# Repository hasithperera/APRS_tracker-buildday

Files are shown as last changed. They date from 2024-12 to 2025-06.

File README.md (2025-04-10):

# APRS tracker-build day

- This project is designed as an out reach project under the WVU Amateur radio club - High altitude ballooning grand awarded Fall 2024
- The main goal was to design a system allowing users to send APRS location packets

---
## V1.1 - APRS beacon

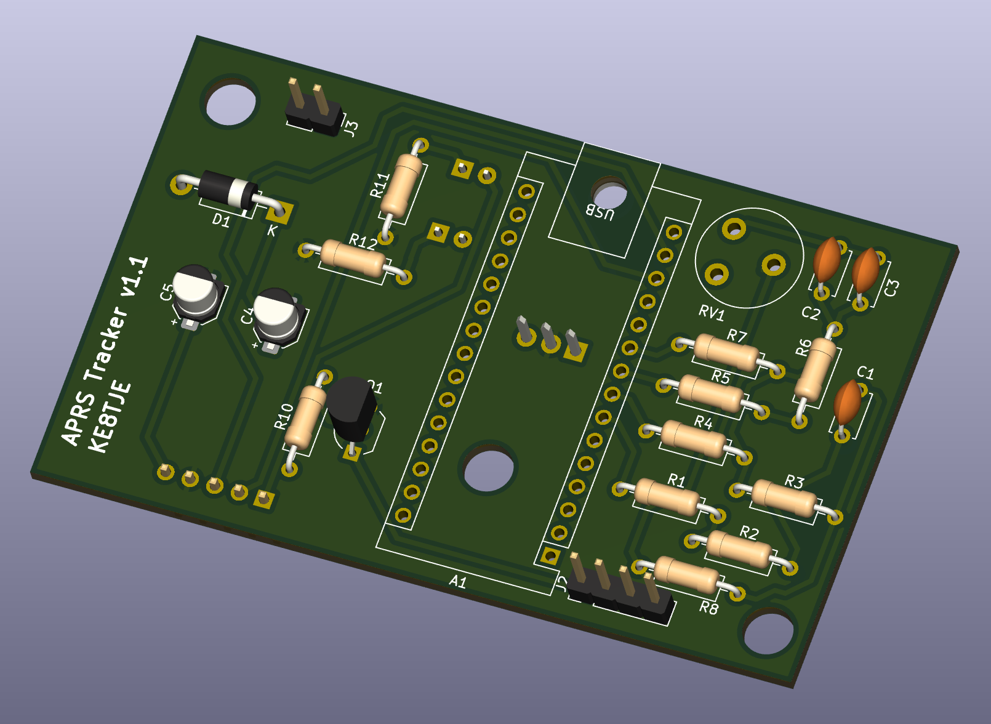
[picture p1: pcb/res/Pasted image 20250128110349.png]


- [Build instructions](pcb/README.md) - Partially completed
---
## Bluetooth KISS TNC - v 1.0

- Based on the interest, we added a part 2 for the build day that was developed for advanced users who needed APRS decode capabilities.
- A self powered KISS TNC PCB was designed to carry existing firmware.
	- Initial testing with APRSDroid and YAAC showed promising results
- V1 PCB for the APRS KISS TNC 

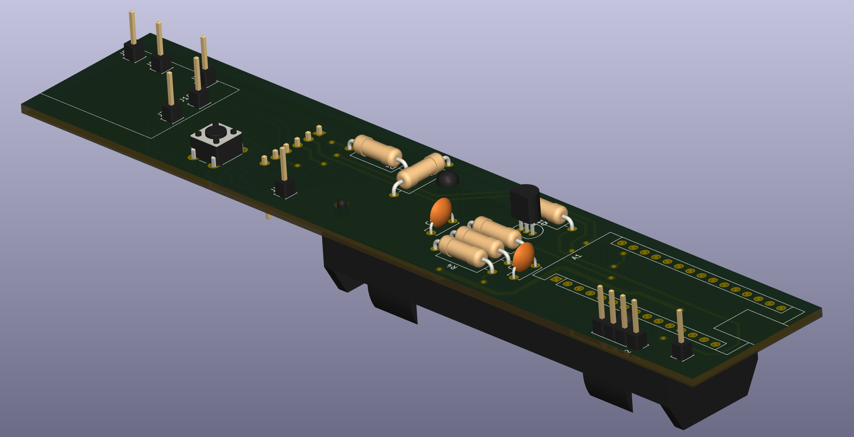
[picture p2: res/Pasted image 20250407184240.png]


---
## Project progress

- November 2024 - Reached out to local clubs on interest and participation
- December 2024 - Basic prototype was tested 
- January 2025 - v1.1 production 
- March 2025 - Software was finalized to allow consistent operation 
- April 2025 - BT KISS TNC v1 PCB added 

*Last edited: April 09 by KE8TJE*

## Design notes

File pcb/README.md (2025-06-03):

# PCB Design updates 

## V1.1 



---
## Build guide 

- Follow the component list below and populate the PCB with components 
- Note 2 changes:
	- the 2N2222 needs to be replaced by a BS170 MOSFET
	- Bridge the Pins **D2** and **D3** on the Arduino
- Once you have every thing soldered in connect power via the USB C connector
	- You should see the power led light up on the arduino
	- Power led on the GPS module
- Once you have confirmed power to all the components follow the programming guide 

---
## Component list

| **Symbol** | **Value** |
| --- | --- |
| C1 | 100n |
| C2,C3 | 4.7u |
| C3,C4 | pol smd |
| D1 | 1n4001 |
| Q1 | 2N2222/BS170 |
| R1 | 6.2k |
| R2 | 2k |
| R3 | 270 |
| R4 | 3.9k |
| R5 | 1.2k |
| R6-R8 | 1k |
| R10 | 2.7k |
| R11,R12 | 330 |

---
## Program instructions

- Open up the Arduino code provided
- to install the Aprs library go to: Tools > Manage Libraries....
	- Search for `LibAPRS` and install the library by Baris DINC
- Once you have the library installed compile the program and it should compile without errors
- Change `line 45` to add your call
### Basic radio interface testing

- Once the Arduino is properly programmed on power on the Radio will be keyed up 2 times as a test. 
	- If this step fails: check your connectors and check your MOSFET.
- To test the system indoors without GPS lock uncomment `line 30`, this will enable a simulate mode where GPS data is being. artificially provided 
- Once the second count reaches the value set in `APRS_TX_offset_utc_sec` your radio will transmit an APRS packet.
	- Radio should key down automatically
	- It has been repoted with some radios this may not happen and this was often observed when there was an extended length of cable involved
		- adding a ferrite bead would potentially solve the issue
		- if not using a separate external antenna should help
- NOTE: change the `APRS_TX_offset_utc_sec` to some random value. This is the time your specific APRS unit will transmit. Since its on simplex we don't want every one to TX at the same time. 
- once you have completed testing comment out `line 30` congratulations now you have a working APRS beacon 

if you have questions please reach out to KE8TJE

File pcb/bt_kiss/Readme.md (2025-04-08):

- The Bluetooth KISS TNC implementation schematic and board designs for quick access

## Schematic 

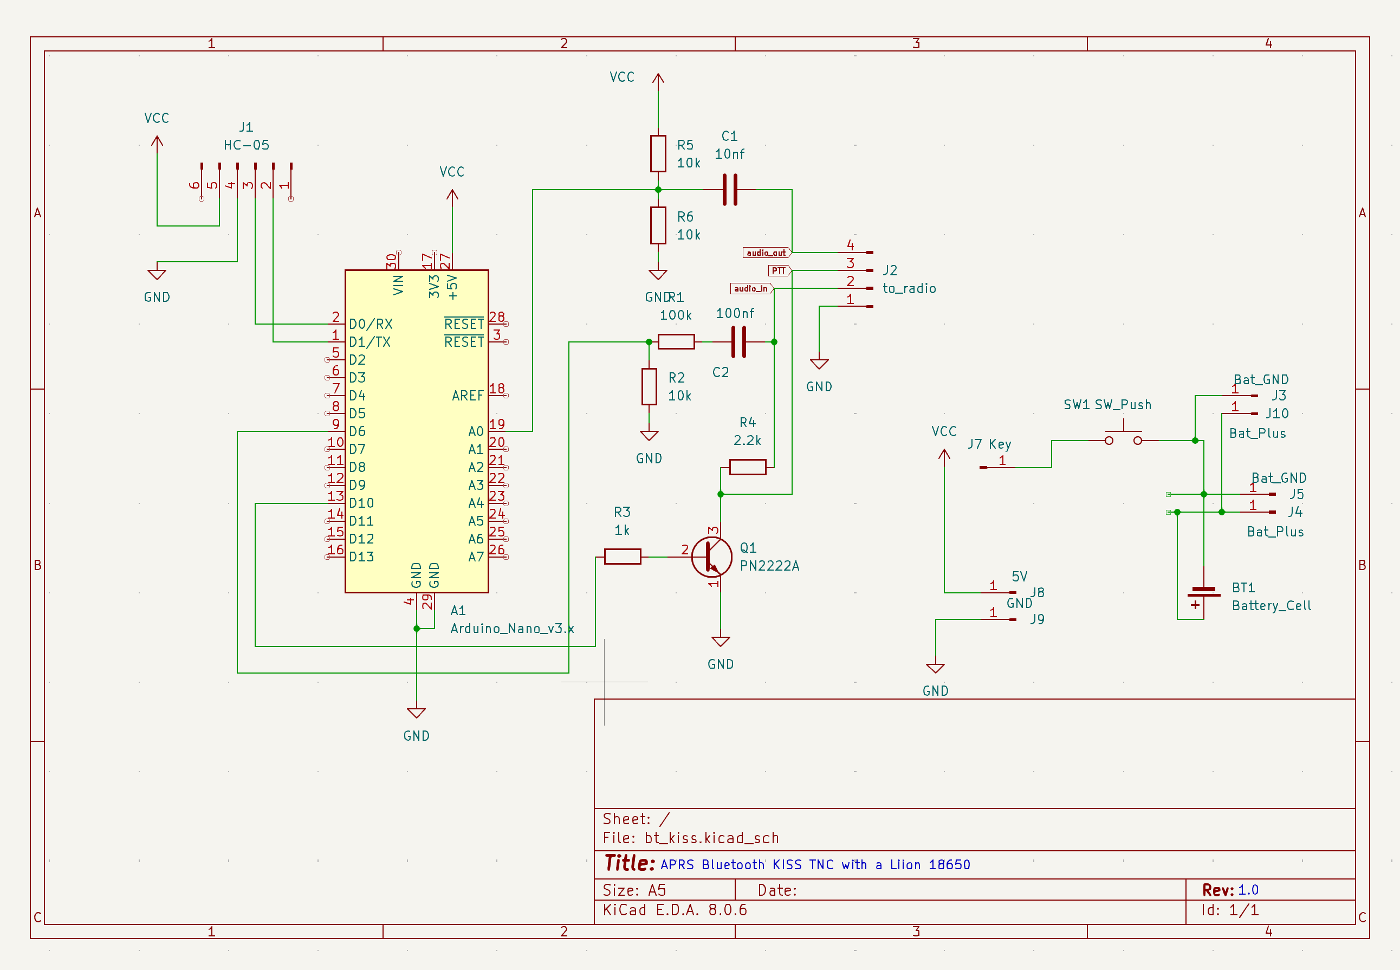
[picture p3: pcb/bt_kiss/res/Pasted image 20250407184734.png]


## Program instructions

- Firmware found [here](https://raw.githubusercontent.com/mobilinkd/tnc1/arduino/images/mobilinkd-473-arduino.hex)
- Programming using the com port: `avrdude -c arduino -p m328p -P /dev/ttyUSB1 -b 57600 -U mobilinkd-473-arduino.hex`
- Programming using a USBasp: `avrdude -p m328p -c usbasp -U flash:w:<filename>.hex`

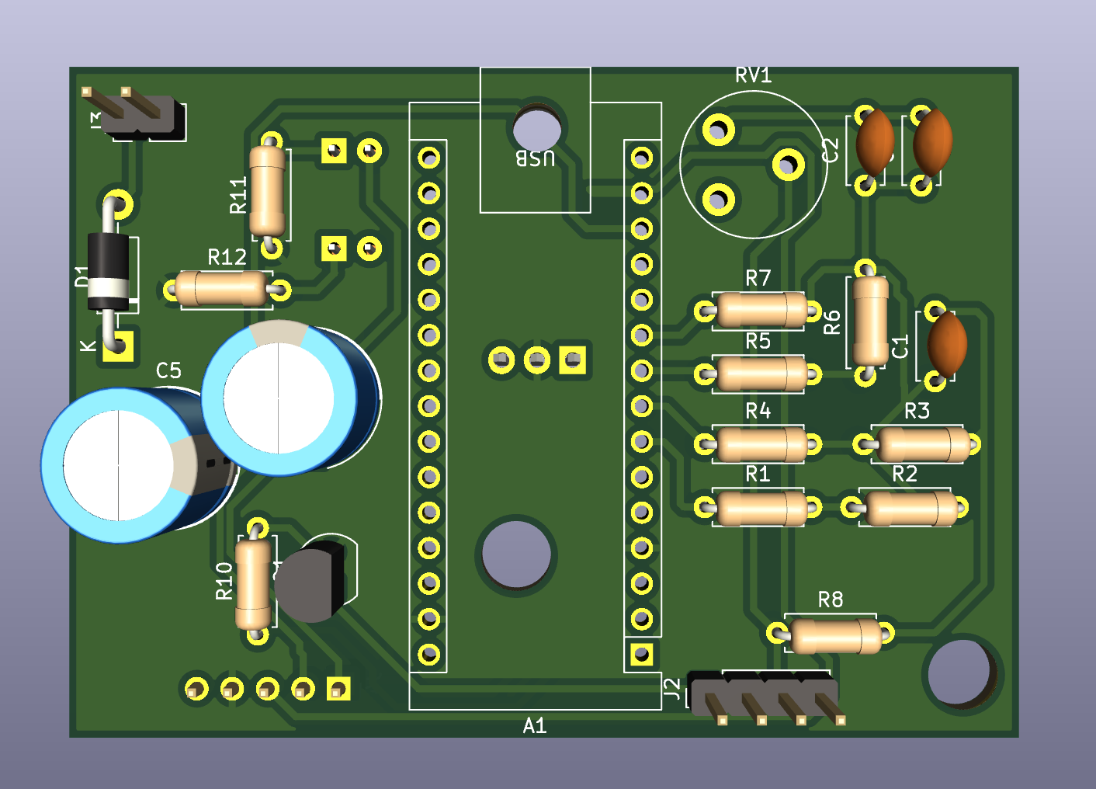
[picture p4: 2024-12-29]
pcb/res/Pasted image 20241229175545.png

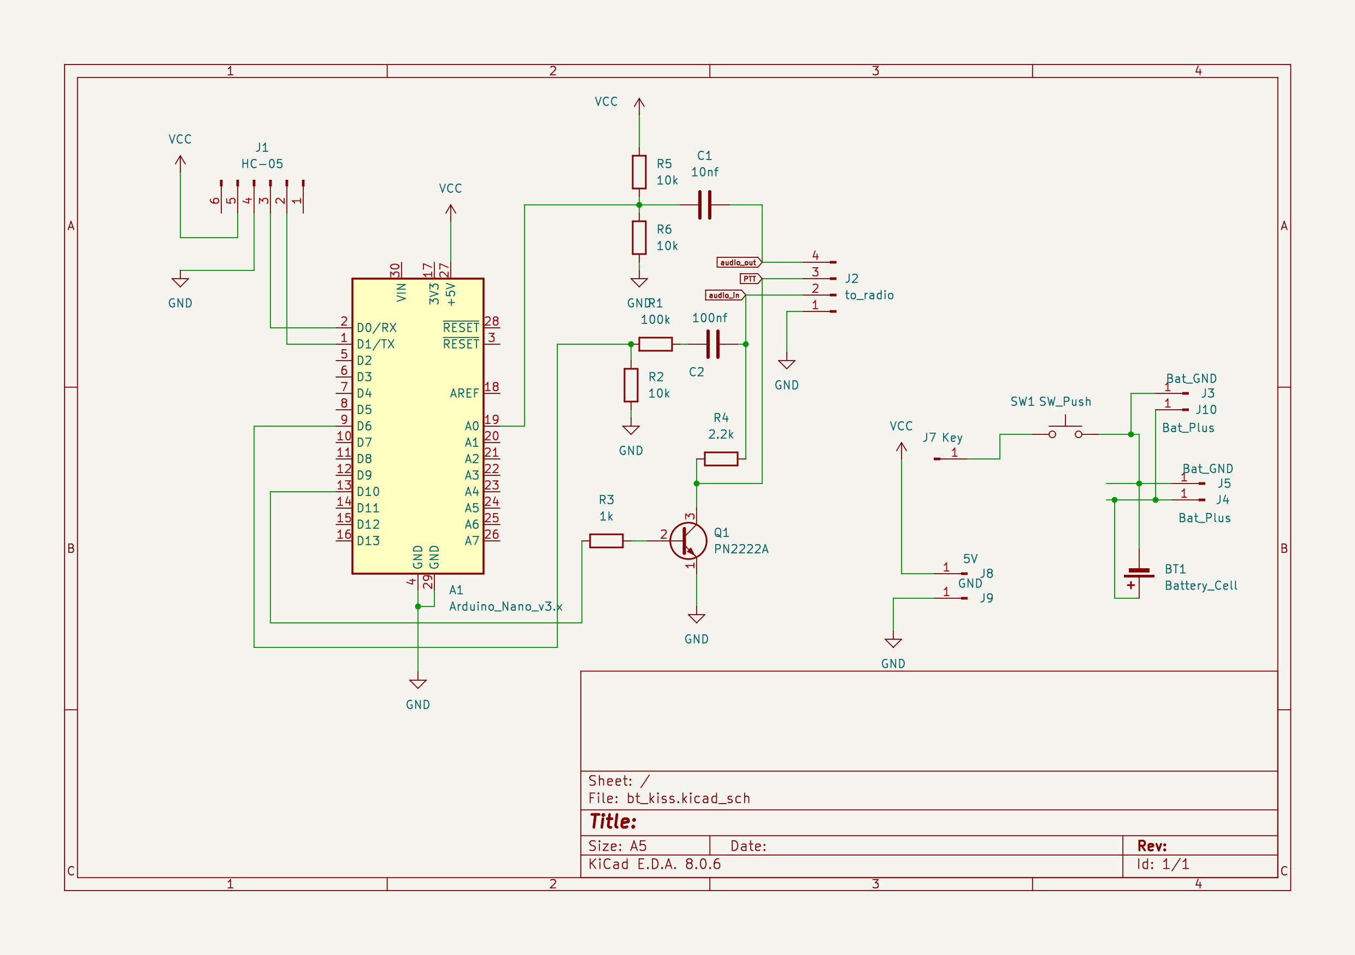
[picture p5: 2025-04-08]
res/Pasted image 20250407184228.png

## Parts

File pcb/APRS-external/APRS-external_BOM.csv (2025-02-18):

Id | Designator | Footprint | Quantity | Designation | Supplier and ref
1 | R8,R7,R6 | R_Axial_DIN0207_L6.3mm_D2.5mm_P10.16mm_Horizontal | 3 | 1k
2 | C5,C4 | CP_Elec_4x4.5 | 2 | C_Polarized
3 | RV1 | Potentiometer_Piher_PT-10-V05_Vertical | 1 | R_Potentiometer_US
4 | R11,R12 | R_Axial_DIN0207_L6.3mm_D2.5mm_P10.16mm_Horizontal | 2 | 330
5 | C2,C3 | D_0805_2012Metric_Pad1.15x1.40mm_HandSolder | 2 | 4.7u
6 | R10 | R_Axial_DIN0207_L6.3mm_D2.5mm_P10.16mm_Horizontal | 1 | 2.7k
7 | R1 | R_Axial_DIN0207_L6.3mm_D2.5mm_P10.16mm_Horizontal | 1 | 6.2k
8 | R4 | R_Axial_DIN0207_L6.3mm_D2.5mm_P10.16mm_Horizontal | 1 | 3.9k
9 | J3 | PinHeader_1x02_P2.54mm_Vertical | 1 | Ext Power
10 | R5 | R_Axial_DIN0207_L6.3mm_D2.5mm_P10.16mm_Horizontal | 1 | 1.2k
11 | D1 | D_DO-41_SOD81_P10.16mm_Horizontal | 1 | 1N4001
12 | C1 | D_0805_2012Metric_Pad1.15x1.40mm_HandSolder | 1 | 100n
13 | A1 | Arduino_Nano | 1 | Arduino_Nano_v2.x
14 | R3 | R_Axial_DIN0207_L6.3mm_D2.5mm_P10.16mm_Horizontal | 1 | 270
15 | J2 | PinHeader_1x04_P2.54mm_Vertical | 1 | To-Radio
16 | Q1 | TO-92_Inline_Wide | 1 | 2N2222
17 | R2 | R_Axial_DIN0207_L6.3mm_D2.5mm_P10.16mm_Horizontal | 1 | 2k
18 | J4 | PinHeader_1x05_P2.54mm_Vertical | 1 | GPS
19 | D3,D2 | LED_D5.0mm | 2 | LED
20 | U1 | TO-220-3_Horizontal_TabDown | 1 | L7805

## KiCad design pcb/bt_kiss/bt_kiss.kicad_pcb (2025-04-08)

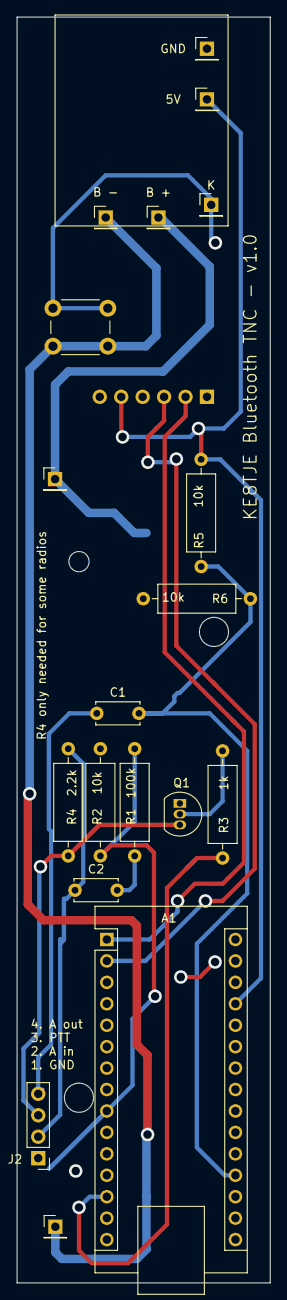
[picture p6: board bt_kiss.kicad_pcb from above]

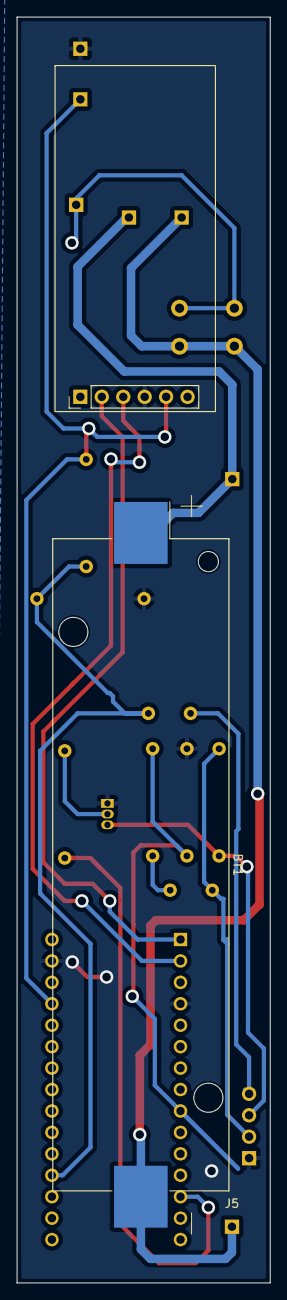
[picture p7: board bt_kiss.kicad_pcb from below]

Board: 2 copper layers, 30.0 x 150.0 mm, 21 parts (2 on the bottom side), 15 nets.

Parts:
5V: 5V; PinHeader_1x01_P2.54mm_Vertical
A1: Arduino_Nano_v3.x; Arduino_Nano
B +: Bat_Plus; PinHeader_1x01_P2.54mm_Vertical
B -: Bat_GND; PinHeader_1x01_P2.54mm_Vertical
BT1: Battery_Cell; BatteryHolder_Keystone_1042_1x18650
C1: 10nf; C_Disc_D5.0mm_W2.5mm_P5.00mm
C2: 100nf; C_Disc_D5.0mm_W2.5mm_P5.00mm
GND: GND; PinHeader_1x01_P2.54mm_Vertical
J1: HC-05; PinHeader_1x06_P2.54mm_Vertical
J2: to_radio; PinHeader_1x04_P2.54mm_Vertical
J4: Bat_Plus; PinHeader_1x01_P2.54mm_Vertical
J5: Bat_GND; PinHeader_1x01_P2.54mm_Vertical
K: Key; PinHeader_1x01_P2.54mm_Vertical
Q1: PN2222A; TO-92_Inline
R1: 100k; R_Axial_DIN0309_L9.0mm_D3.2mm_P12.70mm_Horizontal
R2, R5, R6: 10k; R_Axial_DIN0309_L9.0mm_D3.2mm_P12.70mm_Horizontal
R3: 1k; R_Axial_DIN0309_L9.0mm_D3.2mm_P12.70mm_Horizontal
R4: 2.2k; R_Axial_DIN0309_L9.0mm_D3.2mm_P12.70mm_Horizontal
SW1: SW_Push; SW_PUSH_6mm

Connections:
GND: A1.4 (GND), A1.29 (GND), GND.1, J1.4, J2.1, Q1.1 (E), R2.2, R6.2
unnamed: A1.19 (A0), C1.2, R5.2, R6.1
unnamed: A1.2 (D0/RX), J1.3
unnamed: A1.1 (D1/TX), J1.2
unnamed: A1.9 (D6), R1.1, R2.1
unnamed: A1.13 (D10), R3.1
unnamed: B +.1, BT1.1 (+), J4.1
unnamed: B -.1, BT1.2 (-), J5.1, SW1.2
unnamed: C2.2, R1.2
unnamed: K.1, SW1.1
unnamed: Q1.2 (B), R3.2
PTT: J2.3, Q1.3 (C), R4.1
VCC: 5V.1, A1.27 (+5V), J1.5, R5.1
audio_in: C2.1, J2.2, R4.2
audio_out: C1.1, J2.4

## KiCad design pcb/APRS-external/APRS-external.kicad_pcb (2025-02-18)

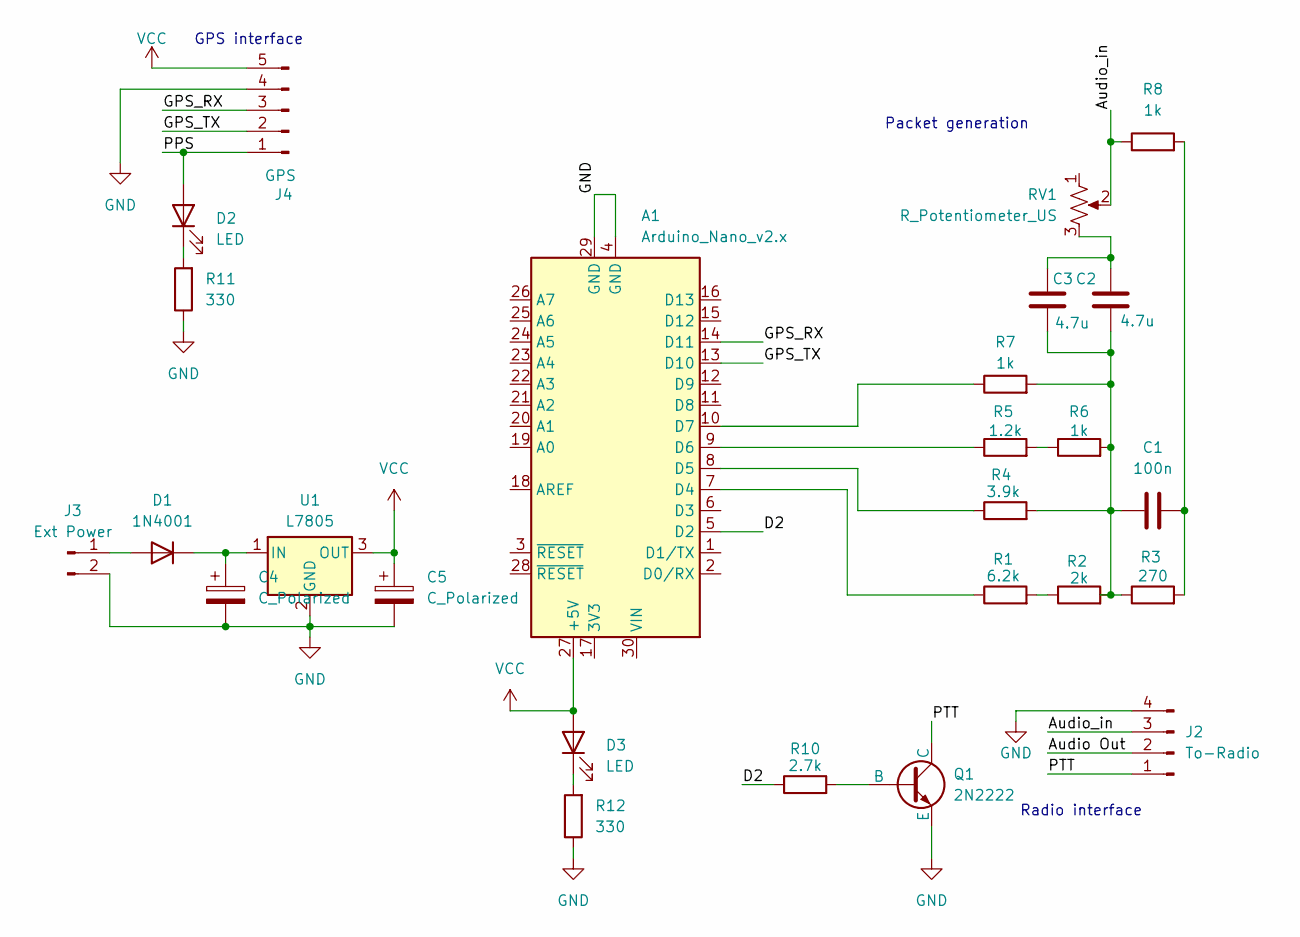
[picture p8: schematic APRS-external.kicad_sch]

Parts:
A1: Arduino_Nano_v2.x; Arduino_Nano
C1: 100n; D_0805_2012Metric_Pad1.15x1.40mm_HandSolder
C2, C3: 4.7u; D_0805_2012Metric_Pad1.15x1.40mm_HandSolder
C4, C5: C_Polarized; CP_Elec_4x4.5
D1: 1N4001; D_DO-41_SOD81_P10.16mm_Horizontal
D2, D3: LED; LED_D5.0mm
J2: To-Radio; PinHeader_1x04_P2.54mm_Vertical
J3: Ext Power; PinHeader_1x02_P2.54mm_Vertical
J4: GPS; PinHeader_1x05_P2.54mm_Vertical
Q1: 2N2222; TO-92_Inline_Wide
R1: 6.2k; R_Axial_DIN0207_L6.3mm_D2.5mm_P10.16mm_Horizontal
R2: 2k; R_Axial_DIN0207_L6.3mm_D2.5mm_P10.16mm_Horizontal
R3: 270; R_Axial_DIN0207_L6.3mm_D2.5mm_P10.16mm_Horizontal
R4: 3.9k; R_Axial_DIN0207_L6.3mm_D2.5mm_P10.16mm_Horizontal
R5: 1.2k; R_Axial_DIN0207_L6.3mm_D2.5mm_P10.16mm_Horizontal
R6, R7, R8: 1k; R_Axial_DIN0207_L6.3mm_D2.5mm_P10.16mm_Horizontal
R10: 2.7k; R_Axial_DIN0207_L6.3mm_D2.5mm_P10.16mm_Horizontal
R11, R12: 330; R_Axial_DIN0207_L6.3mm_D2.5mm_P10.16mm_Horizontal
RV1: R_Potentiometer_US; Potentiometer_Piher_PT-10-V05_Vertical
U1: L7805; TO-220-3_Horizontal_TabDown

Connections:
/Audio Out: J2.2
/Audio_in: J2.3, R8.1, RV1.2
/D2: A1.5 (D2), R10.1
/GPS_RX: A1.14 (D11), J4.3
/GPS_TX: A1.13 (D10), J4.2
/PPS: D2.2 (A), J4.1
/PTT: J2.1, Q1.1 (C)
GND: A1.4 (GND), A1.29 (GND), C4.2, C5.2, J2.4, J3.2, J4.4, Q1.3 (E), R11.1, R12.1, U1.2 (GND)
unnamed: A1.7 (D4), R1.1
unnamed: A1.8 (D5), R4.1
unnamed: A1.9 (D6), R5.1
unnamed: A1.10 (D7), R7.1
unnamed: C1.1, C2.1, C3.1, R2.2, R3.1, R4.2, R6.2, R7.2
unnamed: C1.2, R3.2, R8.2
unnamed: C2.2, C3.2, RV1.3
unnamed: D1.2 (A), J3.1
unnamed: C4.1, D1.1 (K), U1.1 (IN)
unnamed: D2.1 (K), R11.2
unnamed: D3.1 (K), R12.2
unnamed: Q1.2 (B), R10.2
unnamed: R1.2, R2.1
unnamed: R5.2, R6.1
VCC: A1.27 (+5V), C5.1, D3.2 (A), J4.5, U1.3 (OUT)

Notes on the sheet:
GPS interface
Packet generation
Radio interface

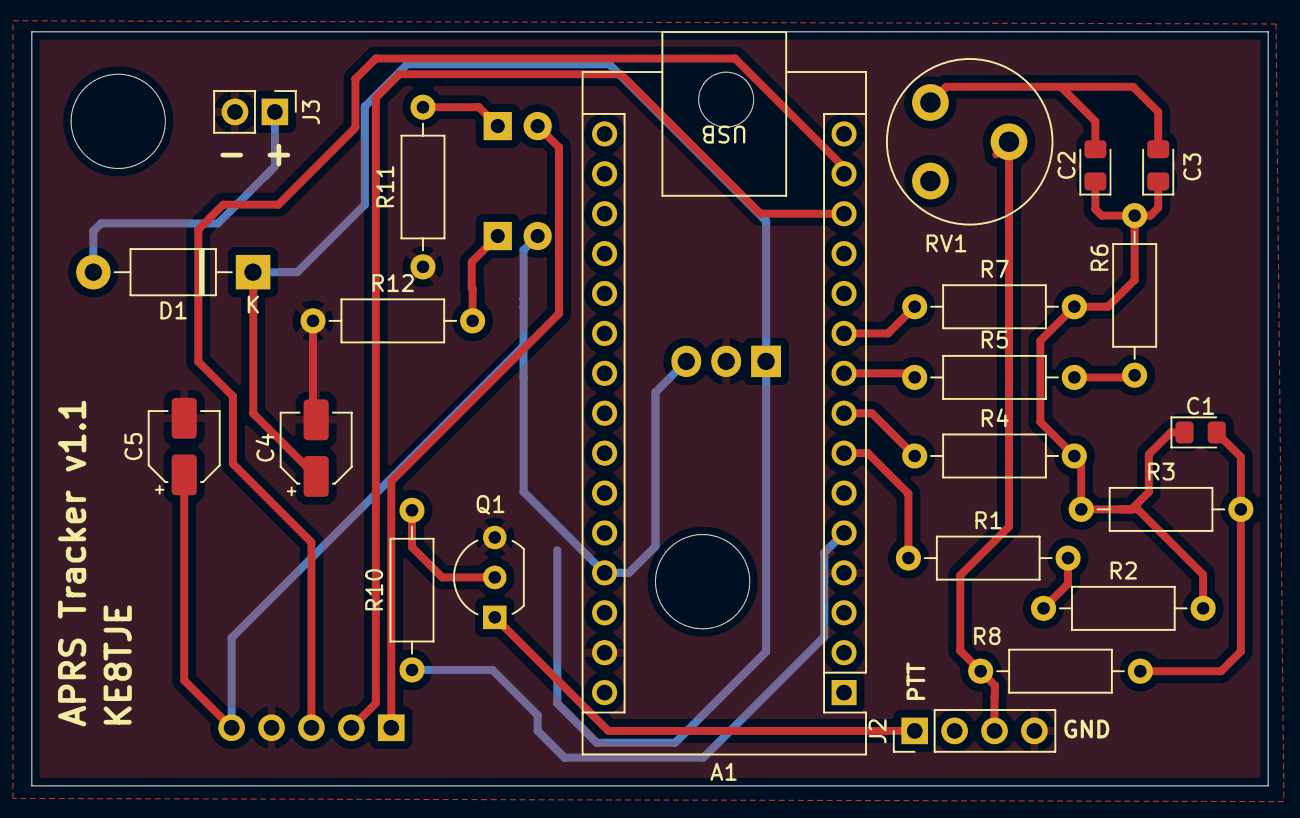
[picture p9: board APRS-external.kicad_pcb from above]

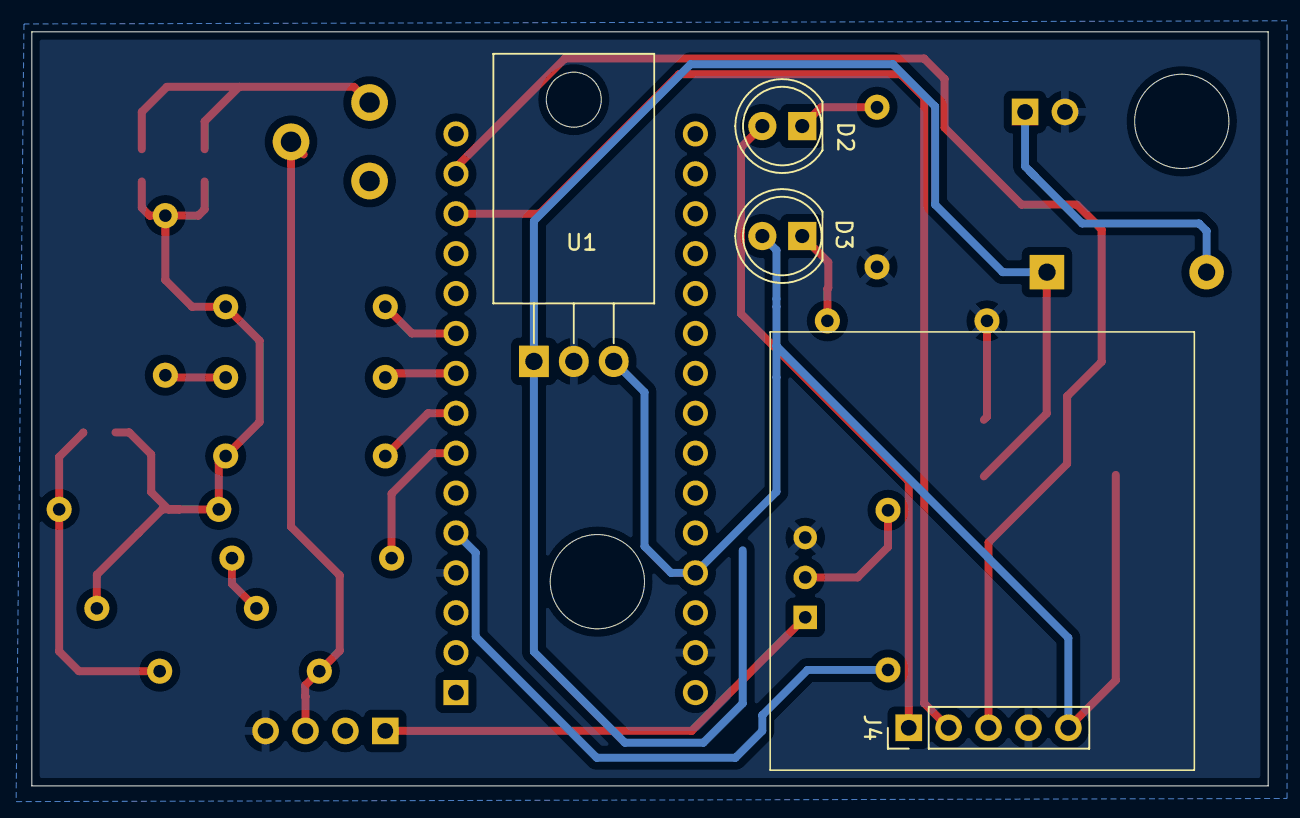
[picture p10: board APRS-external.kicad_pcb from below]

Board: 2 copper layers, 78.7 x 48.0 mm, 26 parts (4 on the bottom side), 22 nets.

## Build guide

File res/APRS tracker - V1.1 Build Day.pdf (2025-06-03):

# APRS Build Day

WVU ARC Build Day Committee: KE8TJE, N3AMK, WV8RQW

## What are we building

- We are building a APRS Tracker/Beacon
- This can only generate AFSK, it needs to be plugged into a radio
- This make accessing APRS easy for a casual user - (a new ham)
- Build day goals:
- Teach you new skills
- Let you test the waters of homebrew/DIY electronics

## A bit of electronics

- Electrical engineers + extras in the room can you’ll tell me how this works ?

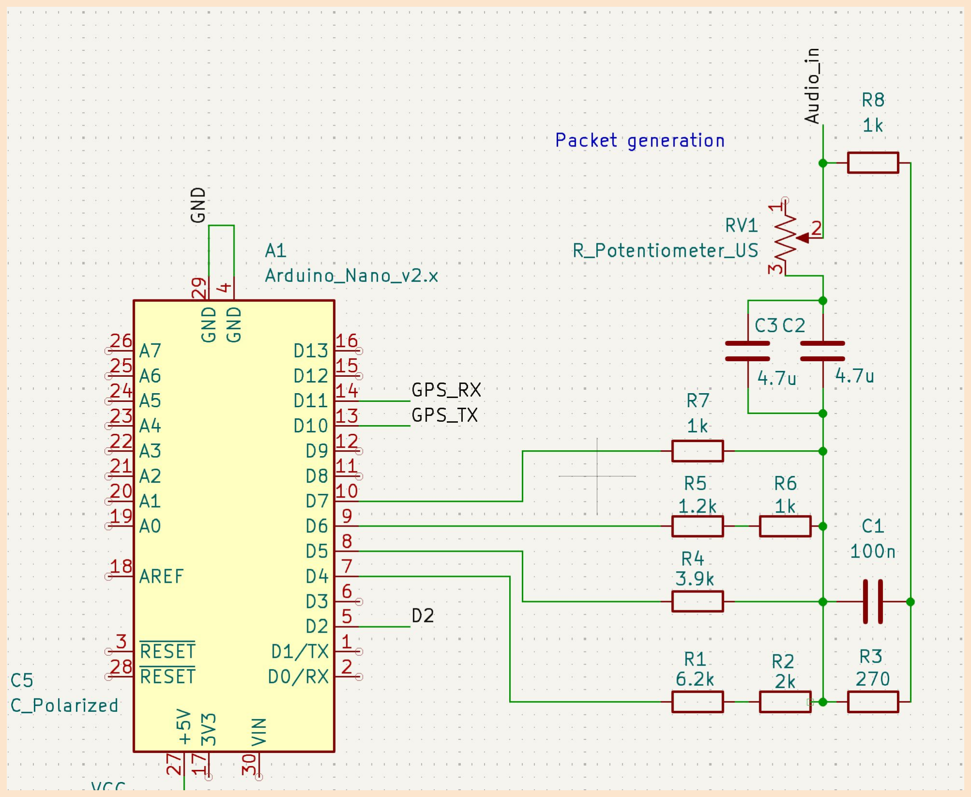
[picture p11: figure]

KE8TJE

## A bit of electronics

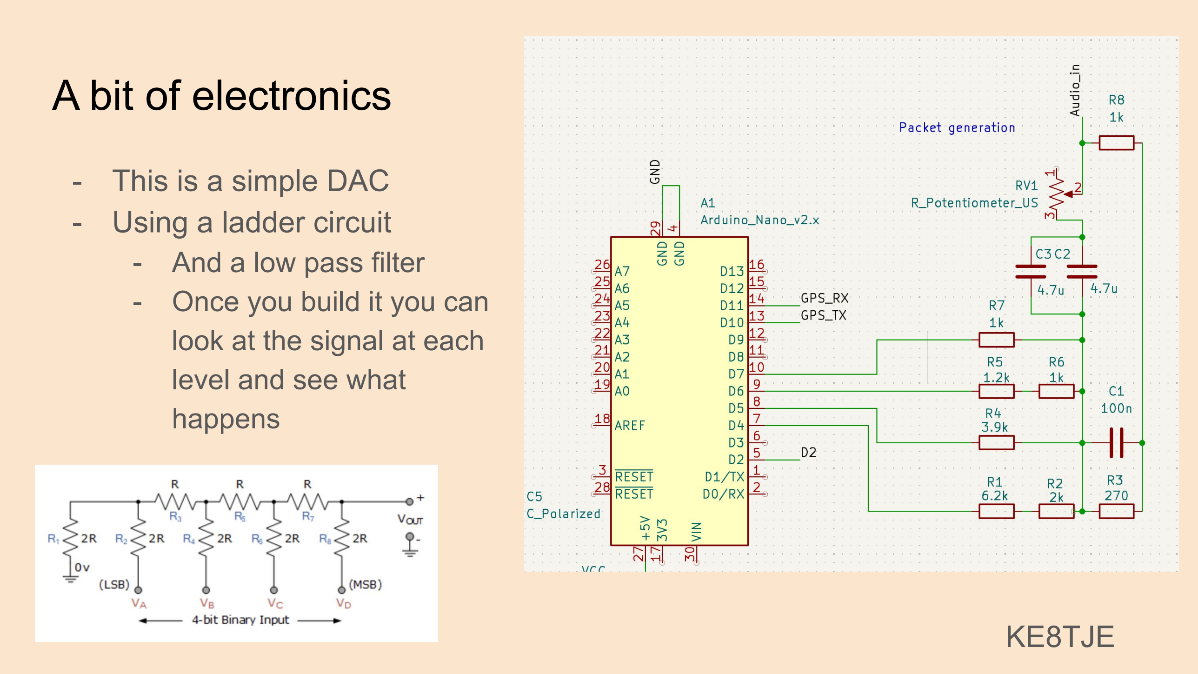
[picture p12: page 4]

- This is a simple DAC
- Using a ladder circuit
- And a low pass filter
- Once you build it you can look at the signal at each level and see what
happens

## APRS - is an AFSK mode

- Fancy way of saying we have only two tones
- 1200 and 2400 Hz that's all we need to generate
- An arduino runs at 20 MHz its more than capable of generating the

signals we would need

- If you want to look in to this, Once you have completed the build probe the

signal with an oscilloscope.

- Ask either the staff and some of us here should be able get it setup

## This is customizable - Some ideas

- Mount it in your car with a HT put an external GPS and 2m antenna
- This can be programmed to send telemetry:
- you can evaluate the battery life of HTs
- Make a small weather station
- Put a BMP280 and you can make it a weather reporting system
- Send other telemetry data from other projects
- This can be powered with a single li-ion battery and a couple of components to be a stand

alone tracker

- This has a GPS, you could use that for other projects, you can convert this in to a WSPR

beacon with some additional hardware

- Hope it will be an endless platform for DIY ham radio digital modes

## Minor correction in the schematic

For the PTT I have indicated a 2N222 NPN transistor. During testing we found that this has a hard time letting go of the PTT.

A ferite on the audio cable might solve it.

Current solution we change it to a BS170 MOSFET

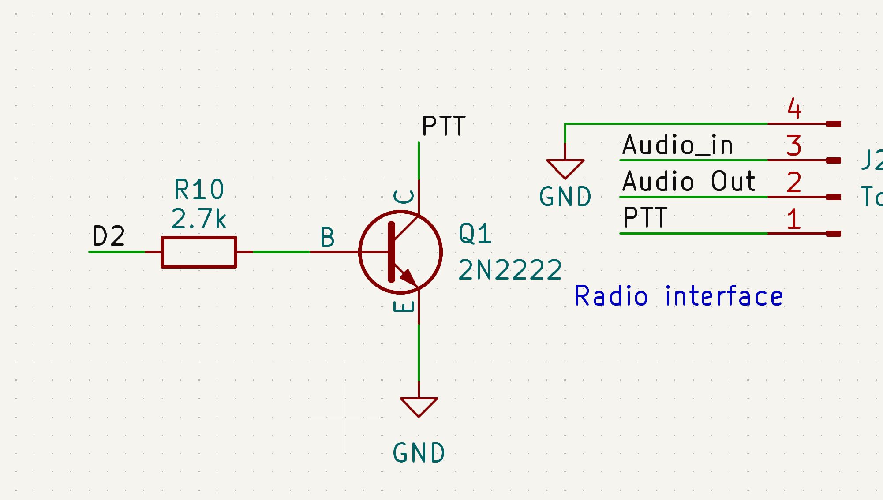
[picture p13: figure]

Pin out luckily works the same way so just replace it and call it good

## Acknowledgement and thank

- The development some part of the build was funded under a grant from NASA West Virginia Space Grant Consortium for STEM outreach and popularization
- Open source hardware and software project
- Support open science / open hardware
- Aidan and Reily for organizing the logistics

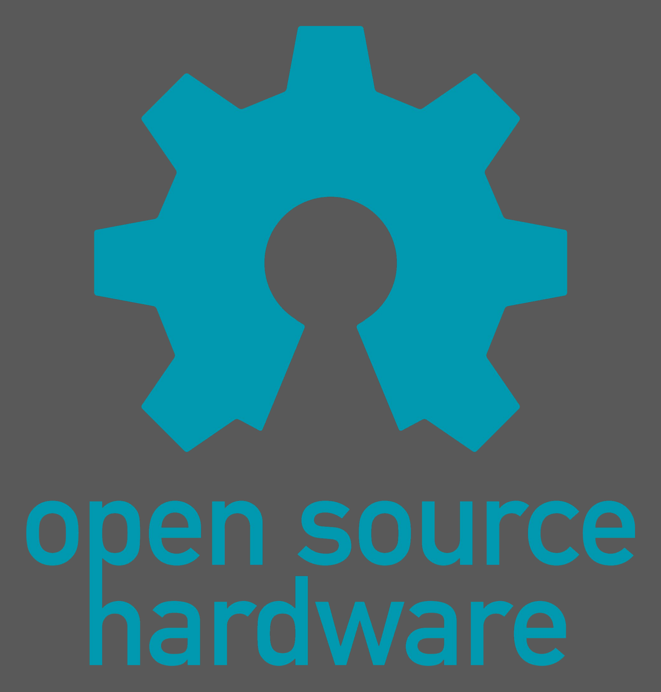
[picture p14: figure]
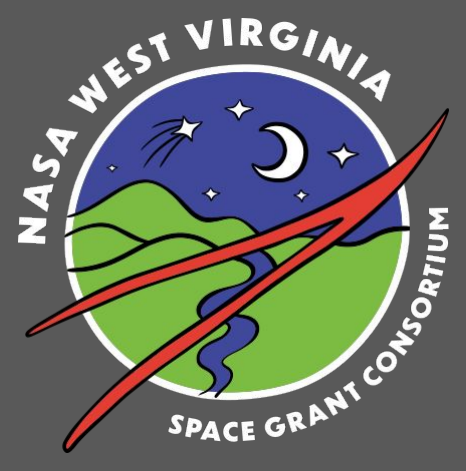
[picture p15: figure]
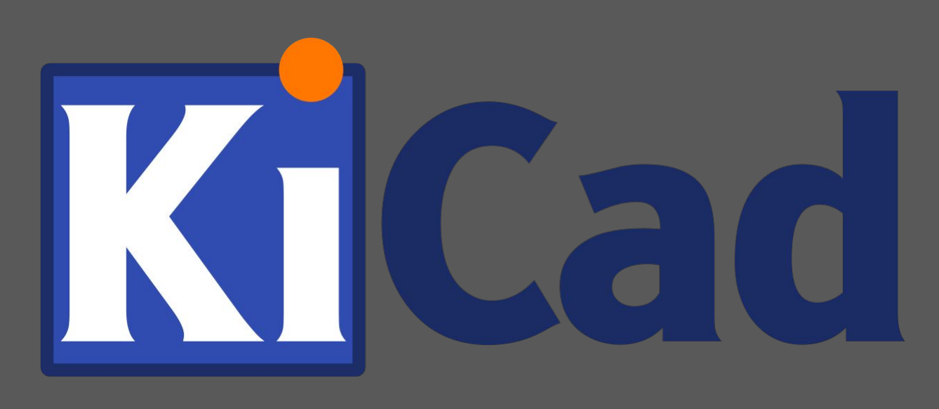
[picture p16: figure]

## Soldering Basics

We can ask the HUB to do it if needed

## Other information

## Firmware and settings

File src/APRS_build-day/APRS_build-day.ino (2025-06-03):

// Author:KE8TJE (ke8tje@gmail.com)
// March 2025

#include <stdio.h>
#include <SoftwareSerial.h>

#include <LibAPRS_Tracker.h>

#define ADC_REFERENCE REF_5V

#define radio_ppt 3  //not needed

//APRS specification
#define symbol '$'
#define SSID 9

#define APRS_TX_offset_utc_sec 14 // this selects what UTC second the packet will be sent out
#define APRS_interval_count 100  // 100 is 1 min

//APRS symbol
// S - shuttle
// < - Bike
// O - Balloon
// > - car

// station SSID
// 9 - Mobile
// 11 - Spacecraft


/*NOTE: Uncomment the following line to put the unit to simulation mode*/
#define sim 1

String packetBuffer;
SoftwareSerial gps(10, 11);  // RX, TX

char Lat[] = "xxxx.xxxxxx";
char Lon[] = "xxxxx.xxxxxxxx";


char test_data[100];

int msg_id = 0;
int msg_valid = 0;
int loc_valid = 0;

char myCALL[] = "KE8TJE";
float freq_tx;

int time_trigger = 0;
float lon, lat, utc;
int sec,min; 

int telemetry[6];
char ext[12];

void setup() {

  Serial.begin(9600);  // for logging and debugging
  Serial.println("[info]APRS Buildday tracker v1.43 - W8CUL/KE8TJE");

  #ifdef sim
    Serial.println("Unit is in Debug mode. GPS data will be simulated");
    Serial.println("For testing only");
  #endif

  pinMode(2,OUTPUT);
  digitalWrite(2,HIGH);
  delay(500);
  digitalWrite(2,LOW);
  delay(500);
  digitalWrite(2,HIGH);
  delay(500);
  digitalWrite(2,LOW);

  //start GPS
  gps.begin(9600);
}

void loop() {

  gps.listen();
  while (gps.available() > 0) {
    String gps_raw = gps.readStringUntil('\n');
    //Serial.println(gps_raw);
    // Valid data: $GPGLL,3938.28486,N,07957.13511,W,191757.00,A,A*7D
    if (gps_raw.substring(0, 6) == "$GPGLL") {
      
      #ifdef sim
        gps_raw = "$GPGLL,3938.28486,N,07957.13511,W,191757.00,A,A*7D";
      #endif
      Serial.println(gps_raw);
      gps_raw.toCharArray(test_data, 100);
      char *p = strtok(test_data, ",");
      update_GPS(p);
    }


  }
}

void base91_telemetry(int a_values){
  // 
  for(int i=0;i<(a_values+1)*2;i+=2){
    ext[i] = (int)(telemetry[i/2]/(91))+33;
    ext[i+1] = (int)(telemetry[i/2]%(91))+33;
  }
  Serial.println(ext);
}

void update_GPS(char *p) {

  p = strtok(NULL, ",");  //lat - <1>

  sprintf(Lat, "%s", p);

  // bug fix in v2
  if (Lat[4] == '.') {
    Lat[7] = '\0';
  } else {
    Lat[8] = '\0';
  }

  p = strtok(NULL, ",");  // lat_dir - <2>
  // handel south
  sprintf(Lat, "%s%s\0", Lat, p);


  p = strtok(NULL, ",");  //lng - <3>
  //formatted string for APRS update

  sprintf(Lon, "%s", p);
  if (Lon[4] == '.') {
    Lon[7] = '\0';
  } else {
    Lon[8] = '\0';
  }
  p = strtok(NULL, ",");           // lon_dir - <4>
  sprintf(Lon, "%s%s\0", Lon, p);  //line to process string for APRS


  p = strtok(NULL, ",");  //time - <5>
  utc = atof(p);

  p = strtok(NULL, ",");  //status- <6>



  // need GPS testing - TJE
  if (p[0] == 'A') {
    msg_valid = 1;
    //togrid(lat, lon);
  }else{
    return;
  }

  #ifdef sim
    sec = (sec+1);
    if(sec==60) sec =0;
  #endif
    
  #ifndef sim
    sec = long(utc) % 100;
    min = long(utc) % 10000 - sec;
  #endif

  Serial.print(min);
  Serial.print(",");
  Serial.println(sec);
  //else {
  // msg_valid = 0;
  //}

  if (sec == APRS_TX_offset_utc_sec & (min % APRS_interval_count) == 0 & msg_valid) {
    Serial.println("[i] Event trigger");
    gps.stopListening();

    //delay(5000);
    location_update(); //typical APRS location packet


    msg_valid = 0;
    gps.listen();
  }
}


int location_update() {

  Serial.println("[info] APRS:start");
  Serial.print(Lat);
  Serial.print(',');
  Serial.print(Lon);

  char comment[30];


  // telemetry functions unused

  telemetry[0] = msg_id;
  telemetry[1] = msg_id+50;
  base91_telemetry(1);    
  // variable name : ext

  // Users please do not chnage the version number

  sprintf(comment, "v1.43 | Testing TJE"); 
  // sprintf(comment, "v1.50|%s|",ext); 
 
  
  Serial.println(comment);

  APRS_init();

  APRS_setPreamble(700);
  APRS_setCallsign(myCALL, SSID);

  APRS_setLat(Lat);
  APRS_setLon(Lon);

  // APRS icon - setting

  APRS_setSymbol(symbol);
  APRS_sendLoc(comment, strlen(comment), ' ');
  while(bitRead(PORTB,5)); 
  delay(800);


  Serial.println("[info] APRS:end");
  msg_id++;
}

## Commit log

2024-12-29 added initial PCB desing
    [APRS-external.kicad_pcb, APRS-external.kicad_sch]
2025-01-27 updated boards
    [APRS-external.kicad_pcb]
2025-01-28 added fixes for physical constraints on the GPS
    [APRS-external.kicad_pcb, APRS-external.kicad_sch]
2025-01-28 updated silk screen print locations
    [APRS-external.kicad_pcb]
2025-01-28 added project label
    [APRS-external.kicad_pcb]
2025-02-18 added BOM and final version made with JLC
    [APRS-external.kicad_pcb, APRS-external.kicad_sch, APRS-external_BOM.csv]
2025-03-13 fixed aprs packet wait
    [APRS_build-day.ino]
2025-04-06 added BT KISS TNC PCB
    [bt_kiss.kicad_pcb, bt_kiss.kicad_sch]
2025-04-07 added 18650 battery holder for the BT KISS TNC PCB
    [bt_kiss.kicad_pcb, bt_kiss.kicad_sch]
2025-04-07 added KISS TNC read me: 2025-04-07 18:54:28
    [bt_kiss.kicad_pcb, bt_kiss.kicad_sch]
2025-04-08 BT TNC v1.1 added ready for production
    [bt_kiss.kicad_pcb]
